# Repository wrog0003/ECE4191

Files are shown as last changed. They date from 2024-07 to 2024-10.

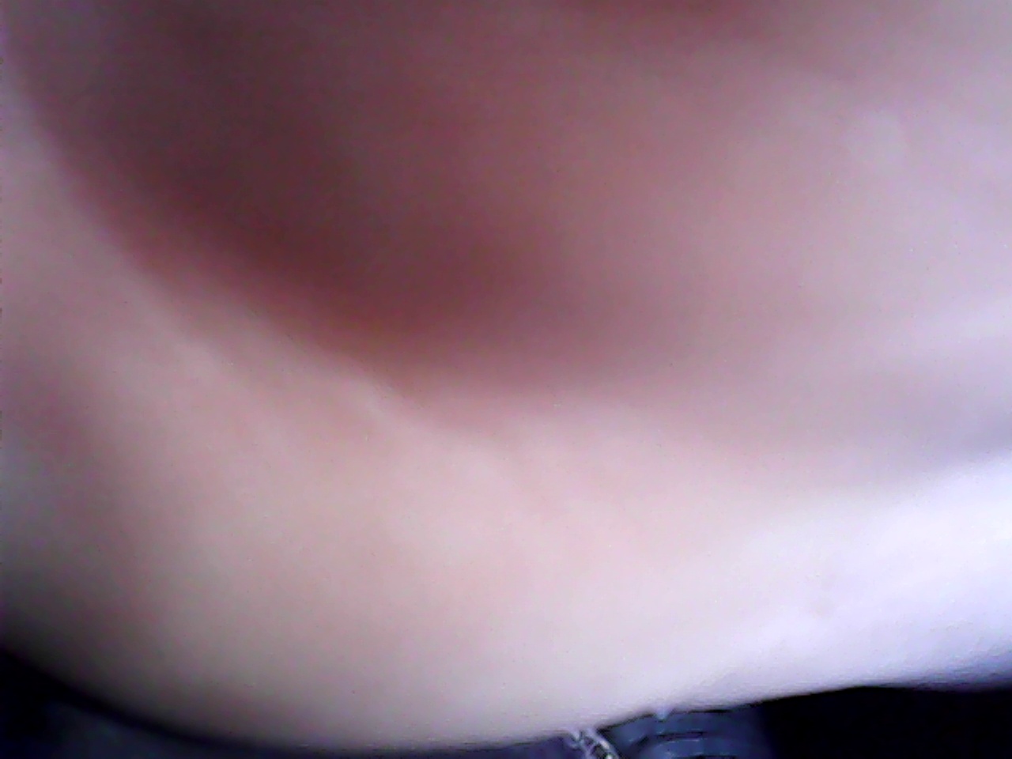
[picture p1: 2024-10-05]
Camera_code/Rpi_Cam.jpg

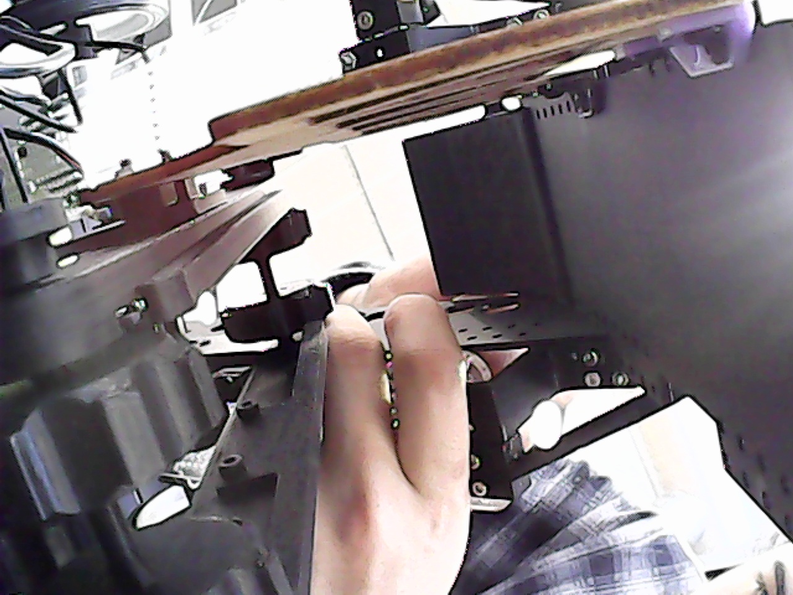
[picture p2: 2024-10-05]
Camera_code/Logitech_Cam.jpg

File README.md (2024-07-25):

# ECE4191
code and other bits and pieces for the project

## Members
Warren Rogan
Emma Vladicic
Richard Owen
Josh Taylor
Ryan Finette

## Purpose
Including all code for ECE4191

## Using rpi 
1. install the vs code extenstion Remote ssh
2. use remote connect to connect to the rpi, make sure you're on the same network 
3. use group23@ECE244
4. password is 1234
5. this will allow you to use the rpi headless

## using git
### own device
download github desktop, this app makes thing much easier
1. Open github desktop and make sure you're in the corect repo
2. Click fetch origin
3. Click this again if there is a pull orign message
4. ensure the pull is successful
5. Code 
6. When finished add a message to the commit entry and press commit
7. Click push 
8. make sure push works
9. done

### rpi
1. open terminal and navigate to the repo top directory
2. run git pull
3. make sure its succesful
4. code
5. when finished open terminal in repo top directory
6. run git commit -a 
7. add a commit comment and press ctrl s
8. press ctrl x to exit nano
9. run git push 
10. make sure this works 
11. done

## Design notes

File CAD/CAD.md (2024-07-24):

# ECE4191
CAD files for the project

## Conventions
### File naming

### 

## Purpose
Including all CAD for ECE4191

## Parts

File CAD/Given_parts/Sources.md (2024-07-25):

# ECE4191
CAD files for parts given as part of kit

Raspberry pi zero W: https://grabcad.com/library/raspberry-pi-zero-w-board-1

Raspberry pi 4: https://www.thingiverse.com/thing:4621310/files#google_vignette

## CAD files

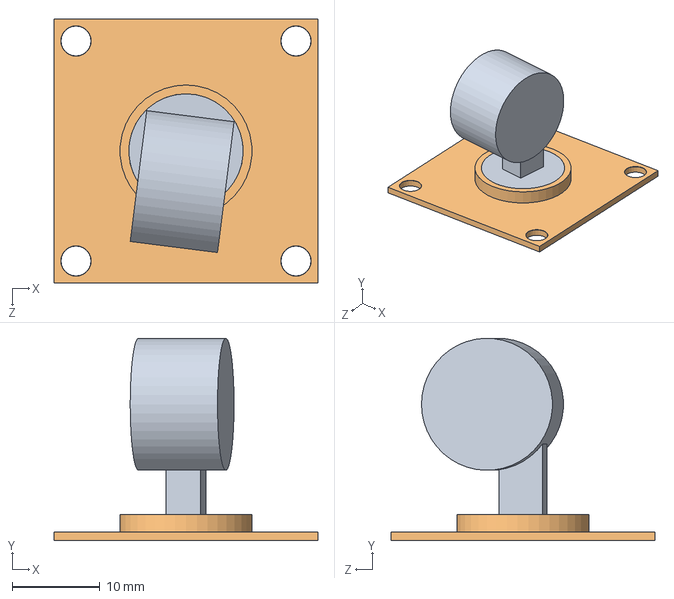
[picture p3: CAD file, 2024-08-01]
CAD/Given_parts/Wheels_Secondary.SLDASM
30.0 x 23.0 x 30.0 mm
Wheels_Secondary_Bottom
Wheels_Secondary_Top

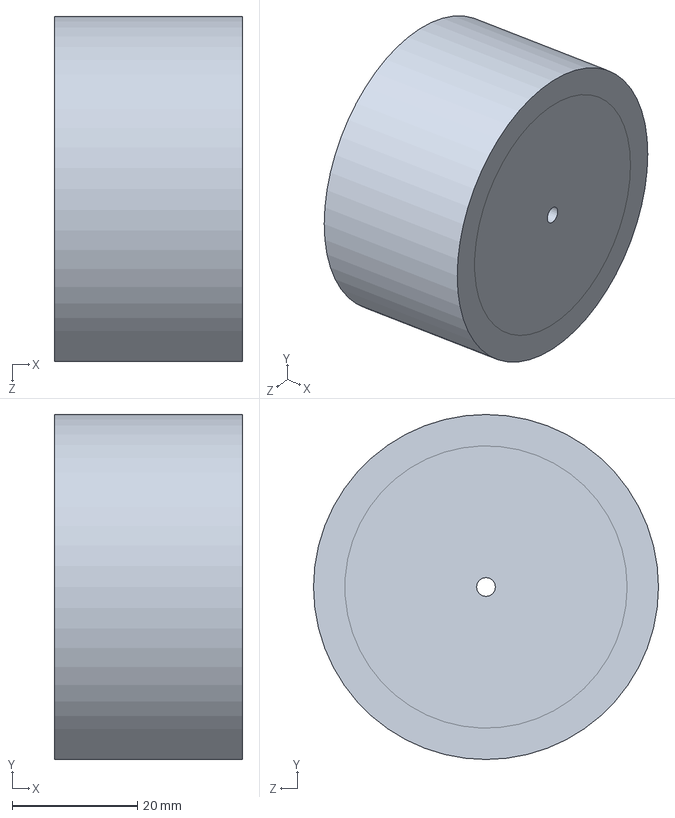
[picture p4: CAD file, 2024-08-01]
CAD/Given_parts/Wheels_Main.SLDPRT
30.0 x 55.0 x 55.0 mm

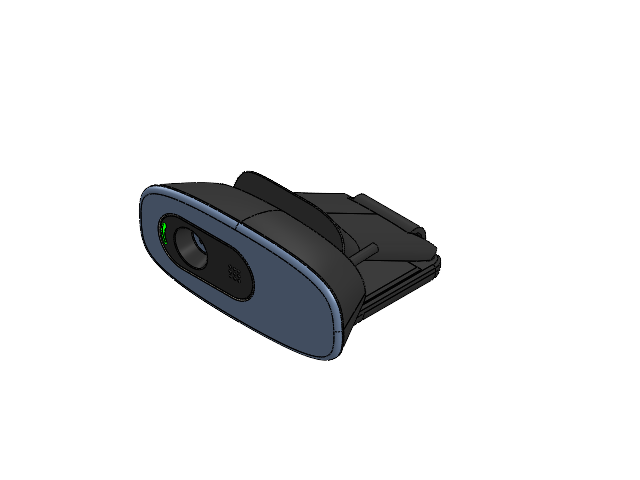
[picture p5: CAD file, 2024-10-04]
CAD/Given_parts/Logitech c270 Assembly.SLDASM
Logitech c270c
Logitech c270b
Logitech c270
Pin camera Mtg Plastic Logi c270

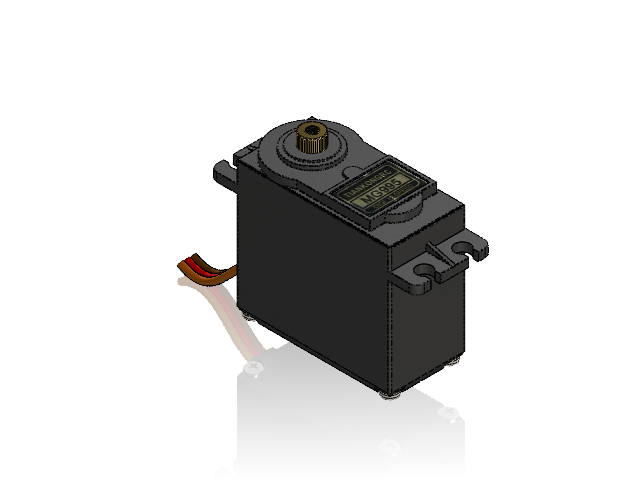
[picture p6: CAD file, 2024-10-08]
CAD/Given_parts/MG995/MG995 Assembly.SLDASM
MG995
Shaft
Wire Boot
Wires
pan head tapping screw_am x 4

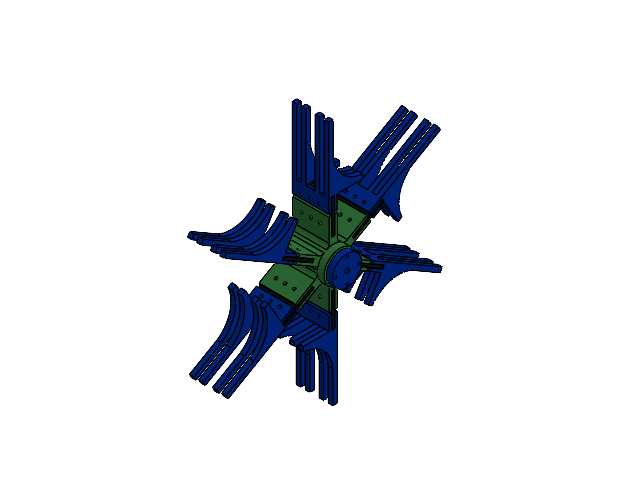
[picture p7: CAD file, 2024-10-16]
CAD/Self_designed_parts/HailMary/HM_Conveyer.SLDASM
HM_HUBCENTRE
HM_HUBCAP
HM_HUBEND
HM_HUBPLATE x 6
HM_HUBCLAW x 6

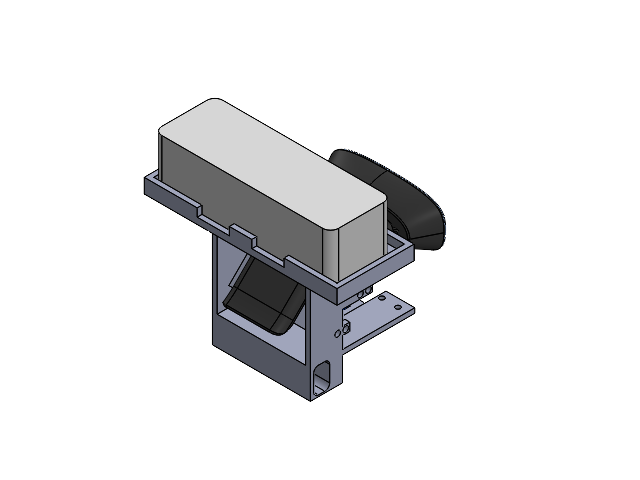
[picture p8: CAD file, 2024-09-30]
CAD/Self_designed_parts/CameraMountSection/CameraMountAss.SLDASM
Battery
NewServoMountSpacer
ServoMount
9gMicroServo
CameraMountBase
CameraMountClamp
Logitech c270
Logitech c270b
Logitech c270c
LipoHolder

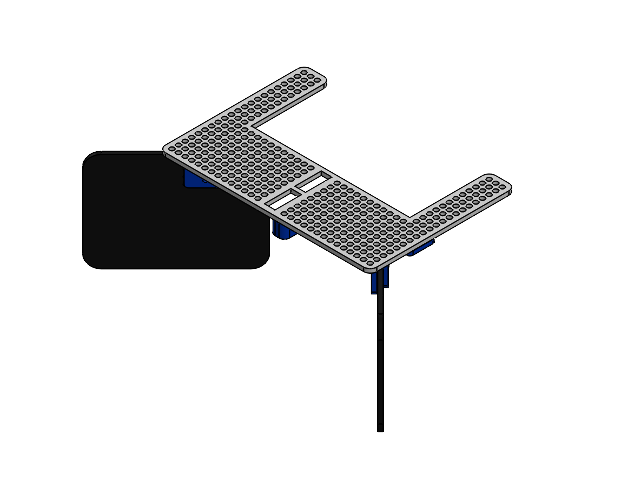
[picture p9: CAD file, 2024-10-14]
CAD/Self_designed_parts/FunnelMount/FunnelAssembally.SLDASM
FunnelPlate
FunnelAdaptor x 4
Funnel x 2
ButtonHolder

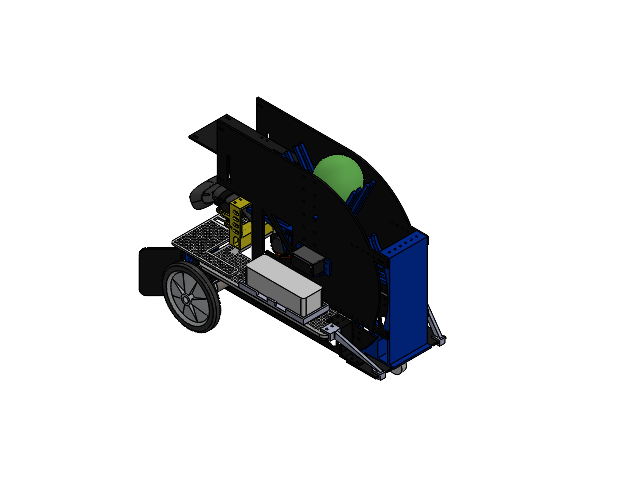
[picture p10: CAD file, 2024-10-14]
CAD/Self_designed_parts/HailMary/HaiMaryAssembly.SLDASM
25d-metal-gearmotor-75-99-encoder.step x 2
MotorMountBracket x 2
MotorMountSpacer x 2
Baseplate
Wheels_Secondary_Bottom
Wheels_Secondary_Top
RampWheelBracket
NewServoMountSpacer
L_Bracket_Chute x 4
BallChute x 2
RearMountBracket_Left
RearMountBracket_Right
Wheel_100mm x 2
MotorMount_Helper x 2
TennisBall(Max)
CameraMountBase
CameraMountClamp
Logitech c270c
Logitech c270b
Logitech c270
Pin camera Mtg Plastic Logi c270
LipoHolder
Battery
MG995
Shaft
Wire Boot
Wires
pan head tapping screw_am x 4
Servo_MG995_Star_horn
SupportBracket x 2
HM_SidePate
HM_HUBCENTRE
HM_HUMCAP
HM_HUBEND
HM_HUBPLATE x 6
HM_HUBCLAW x 6
HM_PLATEMOUNTER
HM_HUDSERVOMOUNT
HM_LOWERRAMP
HM_SidePateRIGHT
HM_ROLLPLATE
HM_UPPERRAMPHOLDER x 2
HM_RAMPADJUSTER x 2
FunnelPlate
FunnelAdaptor x 4
Funnel x 2
ButtonHolder

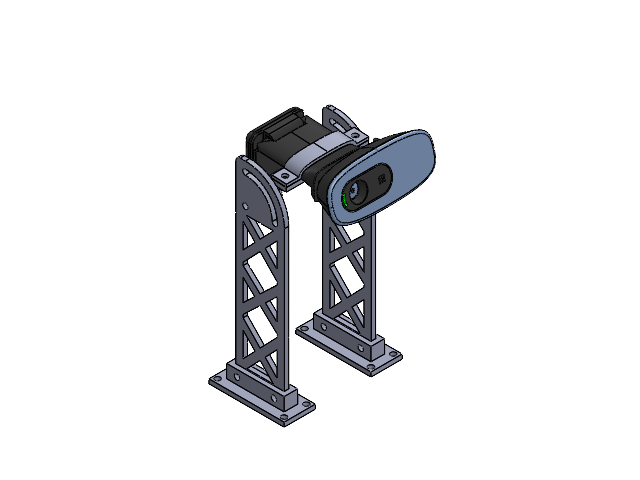
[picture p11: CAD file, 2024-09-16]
CAD/CameraMount/CM_ASS.SLDASM
CM_Base x 2
CM_Vertical x 2
Logitech c270c
Logitech c270b
Logitech c270
Pin camera Mtg Plastic Logi c270
CameraMountClamp
CameraMountBase

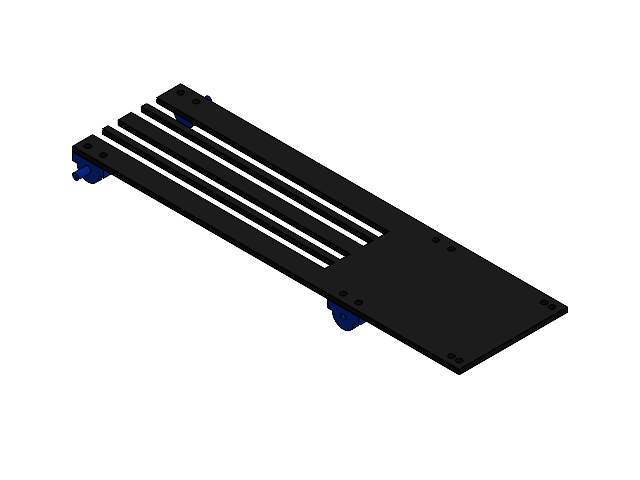
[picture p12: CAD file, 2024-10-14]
CAD/Self_designed_parts/HailMary/HM_RAMP_ASS.SLDASM
HM_ROLLPLATE
HM_UPPERRAMPHOLDER x 2
HM_RAMPADJUSTER x 2

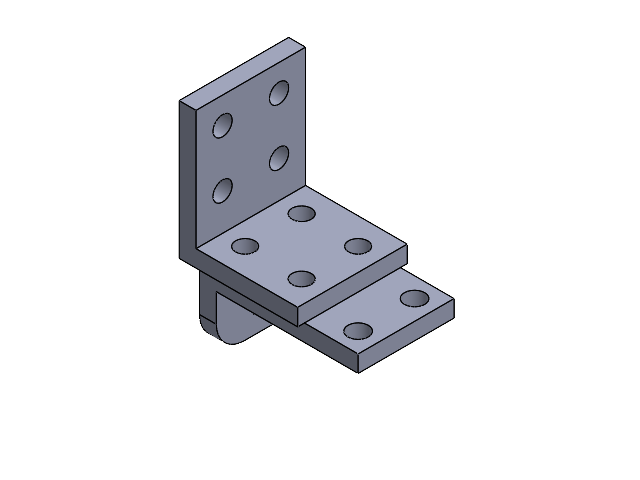
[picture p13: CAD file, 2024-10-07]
CAD/Self_designed_parts/TrackPincherTEST.SLDASM
L_Bracket_Chute
GearMount

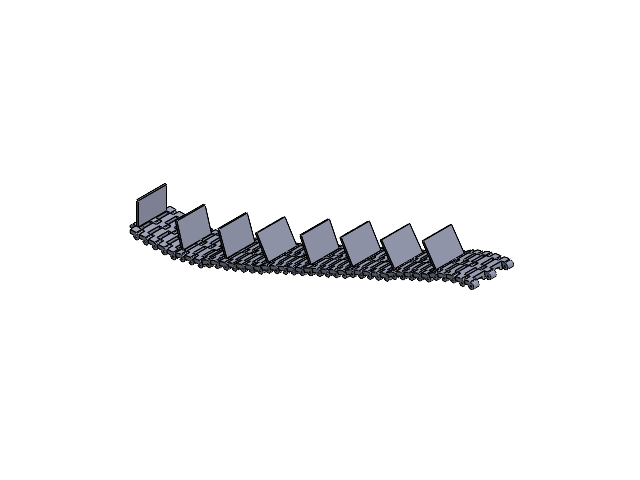
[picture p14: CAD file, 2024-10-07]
CAD/Self_designed_parts/TrackAssembly.SLDASM
Track_2.2_70mm_Pusher x 8
Track_2.2_70mm x 32

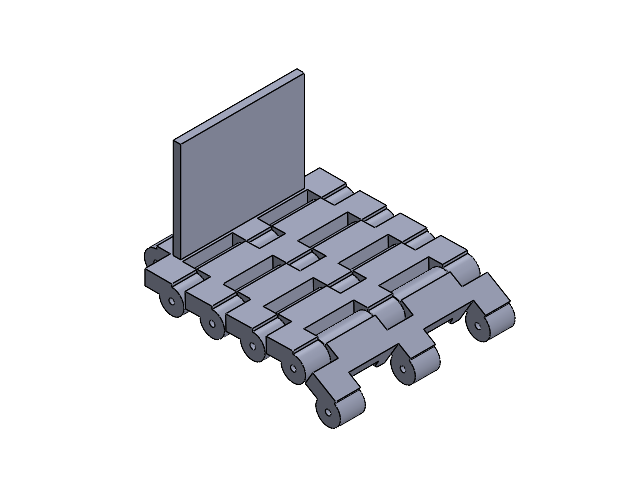
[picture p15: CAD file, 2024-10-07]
CAD/Self_designed_parts/TrackSegment.SLDASM
Track_2.2_70mm_Pusher
Track_2.2_70mm x 4

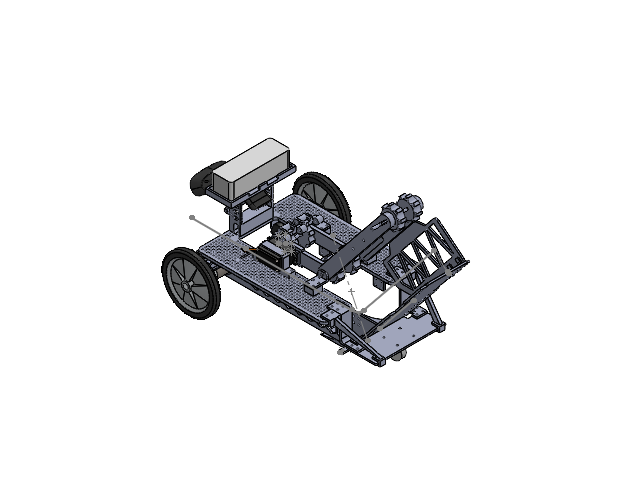
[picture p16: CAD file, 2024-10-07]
CAD/Self_designed_parts/RobotWholeAssembly.SLDASM
25d-metal-gearmotor-75-99-encoder.step x 2
MotorMountBracket x 2
MotorMountSpacer x 2
Baseplate
BallChute
Ramp
Wheels_Secondary_Bottom
Wheels_Secondary_Top
RampWheelBracket
NewServoMountSpacer
L_Bracket_Chute x 4
AngledRampBracket_Left
RearMountBracket_Left
RearMountBracket_Right
GearMount x 3
HorizontalGearSpacer x 2
GearMountSpacer x 3
Wheel_100mm x 2
MotorMount_Helper x 2
DiagonalGearSpacer x 2
RampChute
Track_Gear x 4
Axle x 3
Axle_Cap x 5
RampChuteBracket x 2
RampChuteSpacer
CameraMountBase
CameraMountClamp
Logitech c270c
Logitech c270b
Logitech c270
Pin camera Mtg Plastic Logi c270
LipoHolder
Battery
RampTrackChuck
MG995
Shaft
Wire Boot
Wires
pan head tapping screw_am x 4
Servo_MG995_Star_horn
MG995 Clamp
MG995 Mount
SupportBracket x 2
RampFix
Track_2.2_70mm
Track_Gear_NEW x 2
TrackPincher x 2

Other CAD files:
CAD/Self_designed_parts/ClawLeftAssembly.SLDASM
CAD/Self_designed_parts/ClawRightAssembly.SLDASM
CAD/Self_designed_parts/AlignmentAssembly_GearServo.SLDASM
CAD/Self_designed_parts/PusherAssembly.SLDASM
CAD/CameraMount/CM_Base.SLDPRT
CAD/CameraMount/CM_Mount.SLDPRT
CAD/CameraMount/CM_Vertical.SLDPRT
CAD/CameraMount/CameraLifter.SLDPRT
CAD/CameraMount/CameraLifter.STL
CAD/CameraMount/CameraMountBase.SLDPRT
CAD/CameraMount/CameraMountClamp.SLDPRT
CAD/Drawings/HM_HUBCAP.SLDDRW
CAD/Drawings/HM_HUBCENTRE.SLDDRW
CAD/Drawings/HM_HUBCLAW.SLDDRW
CAD/Drawings/HM_HUBEND.SLDDRW
CAD/Drawings/HM_HUBPLATE.SLDDRW
CAD/Drawings/HM_LOWERRAMP.SLDDRW
CAD/Given_parts/Baseplate.SLDPRT
CAD/Given_parts/Logitech c270.SLDPRT
CAD/Given_parts/Logitech c270b.SLDPRT
CAD/Given_parts/Logitech c270c.SLDPRT
CAD/Given_parts/MG90S horn.SLDPRT
CAD/Given_parts/MG90S horn.STEP
CAD/Given_parts/MG995/MG995.SLDPRT
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

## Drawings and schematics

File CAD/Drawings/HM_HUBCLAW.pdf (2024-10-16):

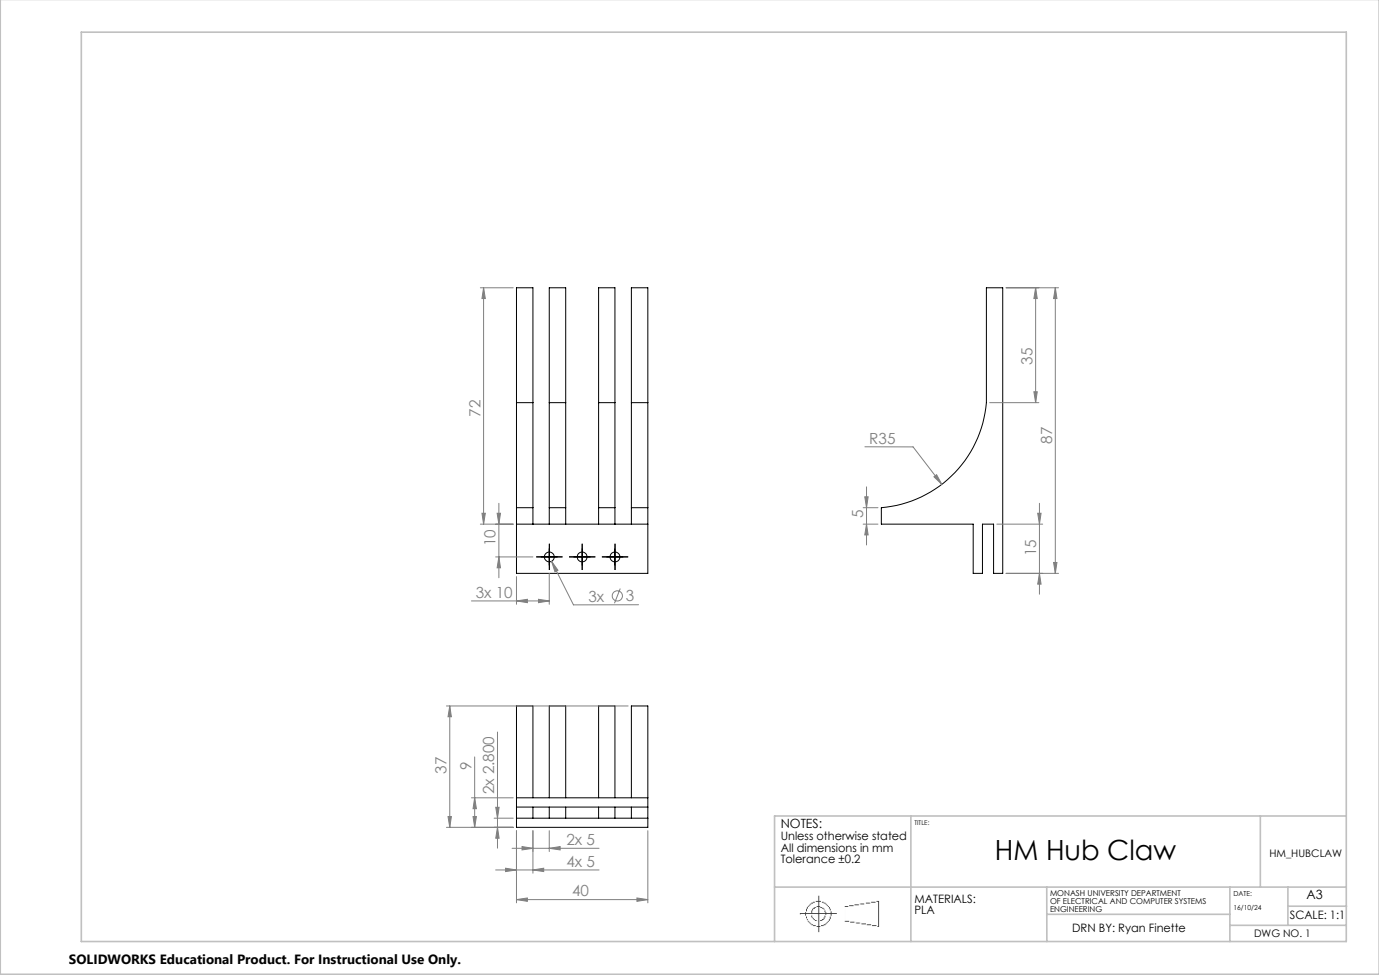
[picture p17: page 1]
DWG NO. 1; SCALE: 1:1

NOTES: Unless otherwise stated All dimensions in mm Tolerance ±0.2 | TITLE: HM Hub Claw | HM_HUBCLAW

MATERIALS: PLA | MONASH UNIVERSITY DEPARTMENT OF ELECTRICAL AND COMPUTER SYSTEMS ENGINEERING | DATE: 16/10/24 | A3

DRN BY: Ryan Finette

SOLIDWORKS Educational Product. For Instructional Use Only.

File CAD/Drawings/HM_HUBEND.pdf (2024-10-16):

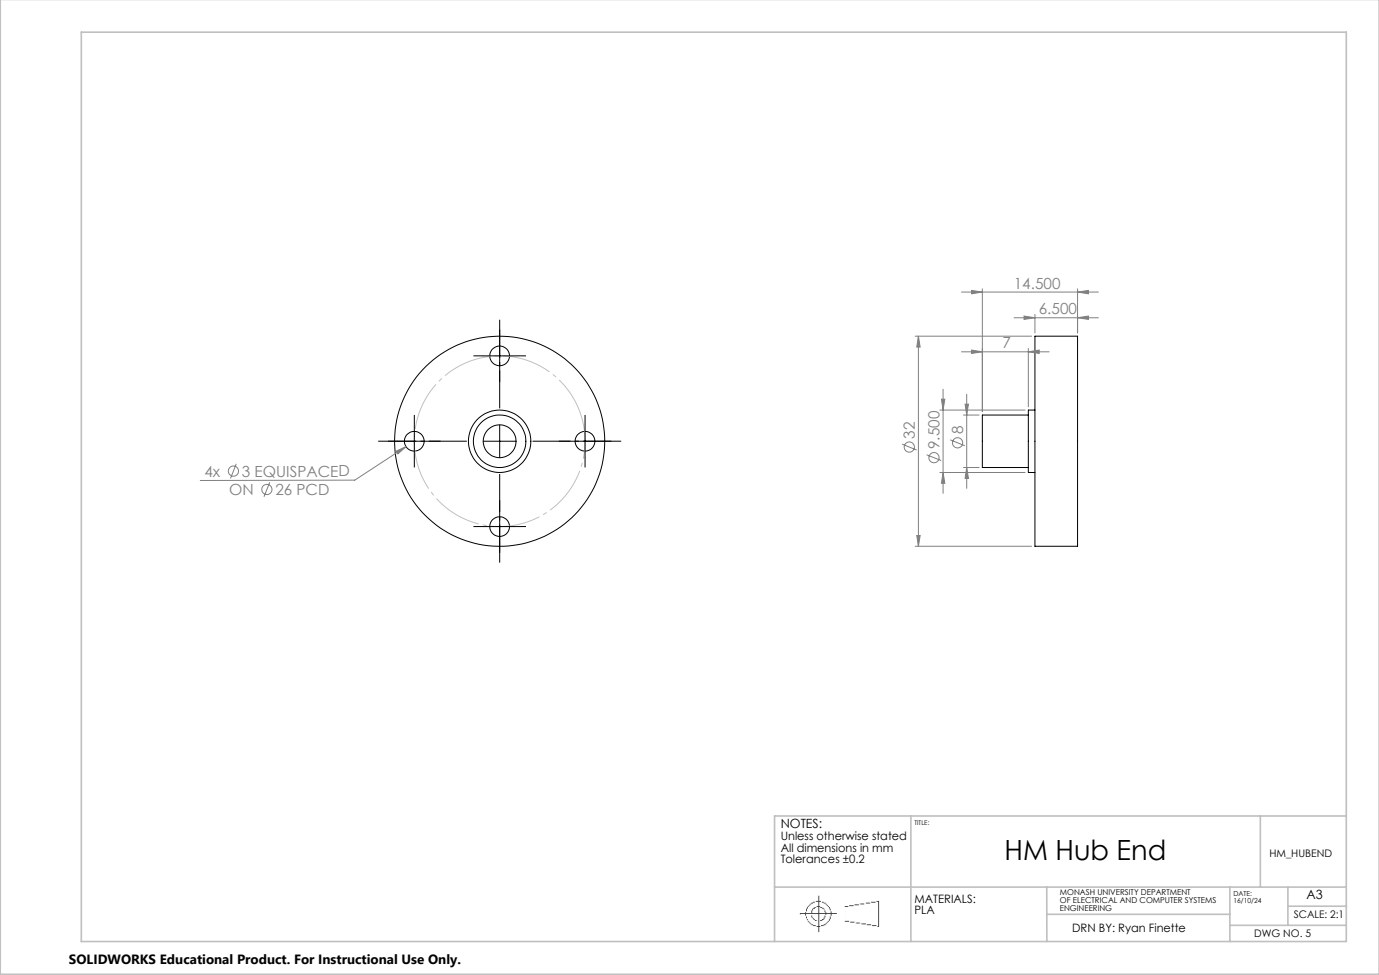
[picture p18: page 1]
4x 3 EQUISPACED ON 26 PCD; DWG NO. 5; SCALE: 2:1

NOTES: Unless otherwise stated All dimensions in mm Tolerances ±0.2 | TITLE: HM Hub End | HM_HUBEND

MATERIALS: PLA | MONASH UNIVERSITY DEPARTMENT OF ELECTRICAL AND COMPUTER SYSTEMS ENGINEERING | DATE: 16/10/24 | A3

DRN BY: Ryan Finette

SOLIDWORKS Educational Product. For Instructional Use Only.

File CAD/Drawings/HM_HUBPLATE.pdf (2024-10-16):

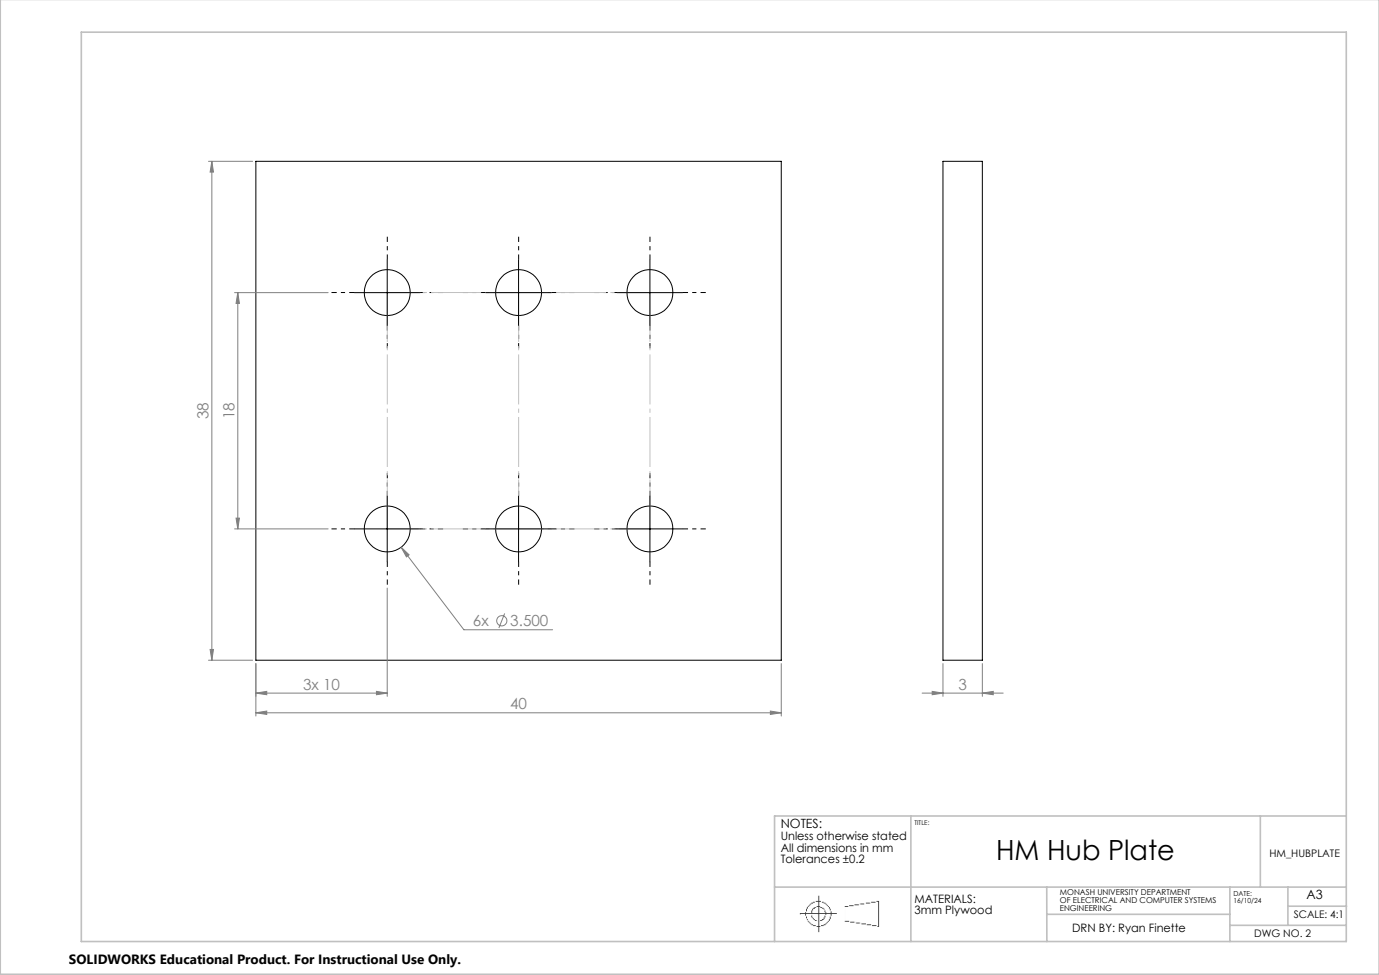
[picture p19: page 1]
DWG NO. 2; SCALE: 4:1

NOTES: Unless otherwise stated All dimensions in mm Tolerances ±0.2 | TITLE: HM Hub Plate | HM_HUBPLATE

MATERIALS: 3mm Plywood | MONASH UNIVERSITY DEPARTMENT OF ELECTRICAL AND COMPUTER SYSTEMS ENGINEERING | DATE: 16/10/24 | A3

DRN BY: Ryan Finette

SOLIDWORKS Educational Product. For Instructional Use Only.

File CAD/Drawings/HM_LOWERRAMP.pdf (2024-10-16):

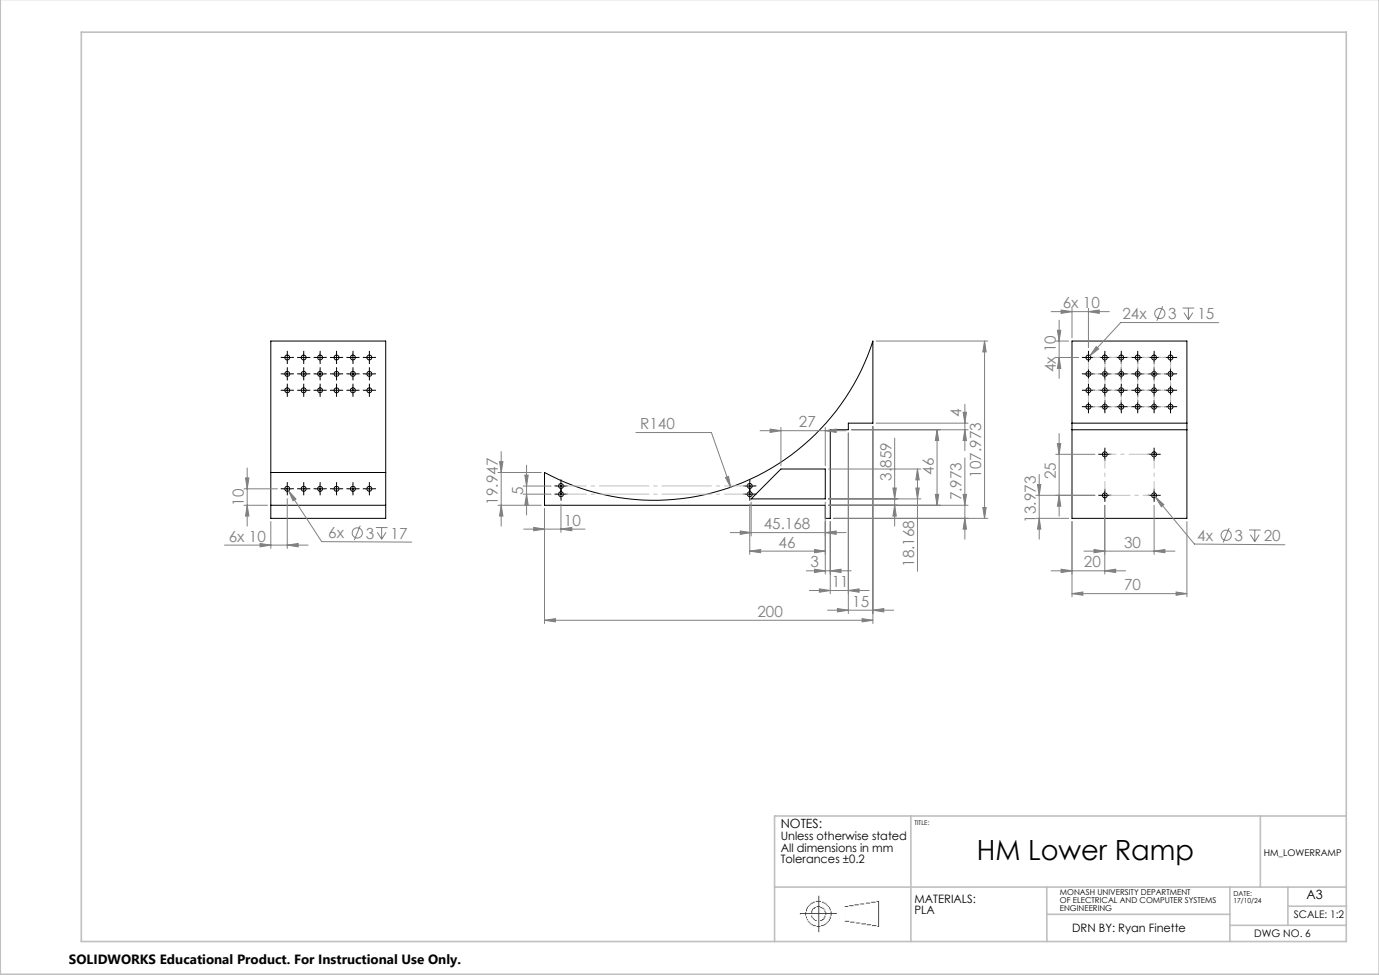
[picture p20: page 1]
DWG NO. 6; SCALE: 1:2

NOTES: Unless otherwise stated All dimensions in mm Tolerances ±0.2 | TITLE: HM Lower Ramp | HM_LOWERRAMP

MATERIALS: PLA | MONASH UNIVERSITY DEPARTMENT OF ELECTRICAL AND COMPUTER SYSTEMS ENGINEERING | DATE: 17/10/24 | A3

DRN BY: Ryan Finette

SOLIDWORKS Educational Product. For Instructional Use Only.

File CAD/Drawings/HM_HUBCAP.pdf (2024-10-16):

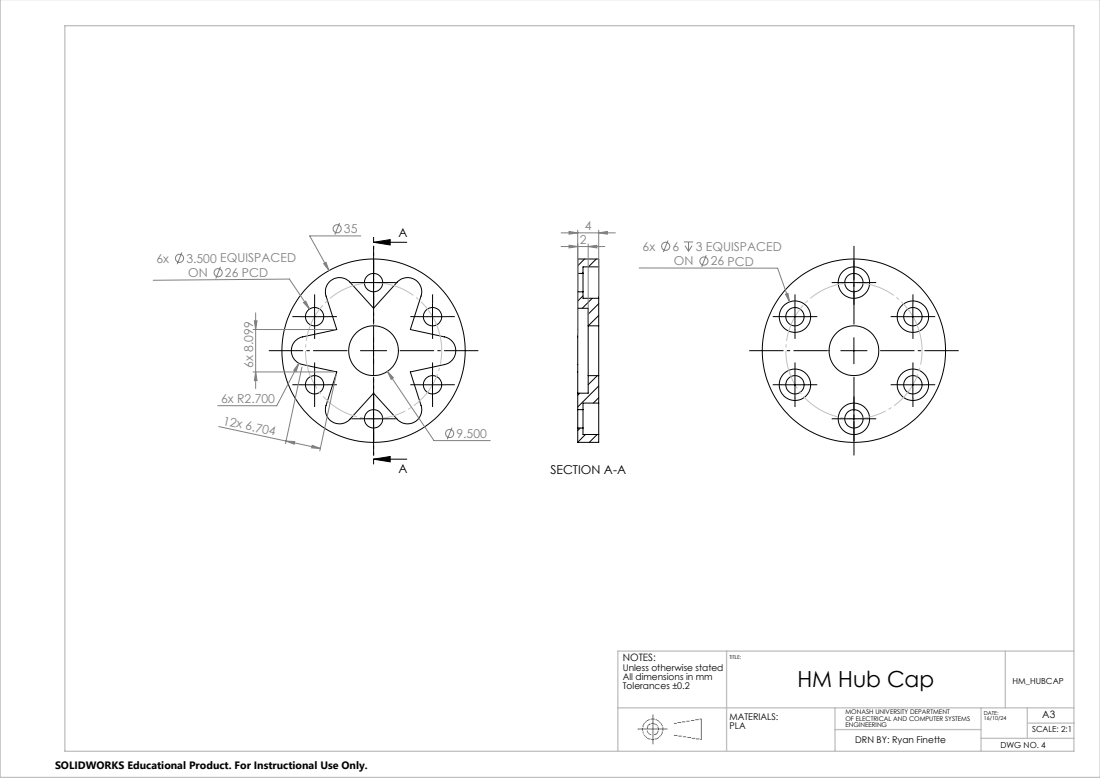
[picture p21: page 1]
6x 3.500 EQUISPACED ON 26 PCD; SECTION A-A; 6x 6 3 EQUISPACED ON 26 PCD; DWG NO. 4; SCALE: 2:1

NOTES: Unless otherwise stated All dimensions in mm Tolerances ±0.2 | TITLE: HM Hub Cap | HM_HUBCAP

MATERIALS: PLA | MONASH UNIVERSITY DEPARTMENT OF ELECTRICAL AND COMPUTER SYSTEMS ENGINEERING | DATE: 16/10/24 | A3

DRN BY: Ryan Finette

SOLIDWORKS Educational Product. For Instructional Use Only.

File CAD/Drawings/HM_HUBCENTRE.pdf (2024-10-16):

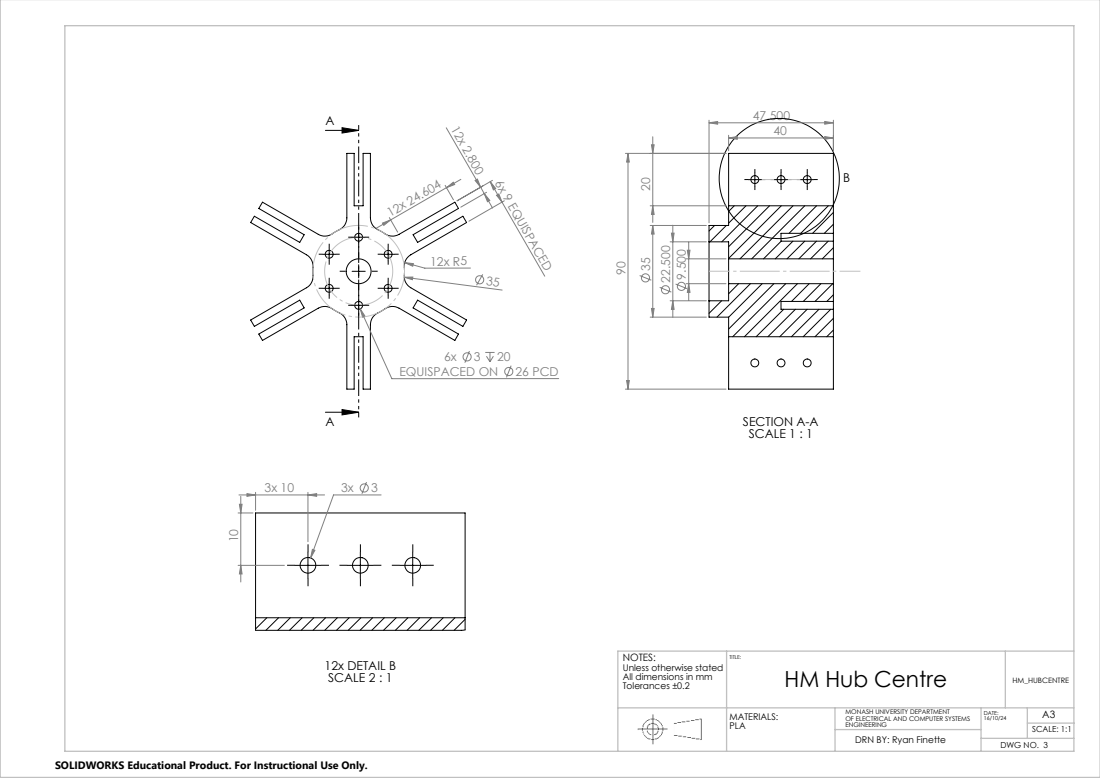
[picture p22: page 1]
6x 9 EQUISPACED; SECTION A-A SCALE 1 : 1; 12x DETAIL B SCALE 2 : 1; DWG NO. 3; SCALE: 1:1

EQUISPACED ON 26 PCD

NOTES: Unless otherwise stated All dimensions in mm Tolerances ±0.2 | TITLE: HM Hub Centre | HM_HUBCENTRE

MATERIALS: PLA | MONASH UNIVERSITY DEPARTMENT OF ELECTRICAL AND COMPUTER SYSTEMS ENGINEERING | DATE: 16/10/24 | A3

DRN BY: Ryan Finette

SOLIDWORKS Educational Product. For Instructional Use Only.

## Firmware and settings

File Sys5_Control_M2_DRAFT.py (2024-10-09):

# overall brains script for robot, written by Emma Vladicic and Warren Rogan 

from ECE4191enums import STATE, DIRECTION, ACTION
from Motor_code.encoderClass import SimpleEncoder
from Sys4_Vision import Sys4_Vision
from Box_detection.box_detection import find_and_goto_box
from gpiozero import Button
from SysC_BallCollection import SysC_BallCollection

from time import sleep, time 
from math import pi, atan2, sqrt, sin, cos

from typing import Tuple

import RPi.GPIO as GPIO
import GLOBALSM1 # for physical values of the robot i.e. wheel diameter, distance b/w wheeels etc   

# Define important variables 

# Define clockwise and anti-clockwise as Boolean variables 
ANTICLOCKWISE = False
CLOCKWISE = True

# Define physical GPIO pins on the Rpi 
# Motor Left (to drive motors)
motor1a = 23
motor1b = 24

# Motor Right (to drive motors)
motor2a = 17
motor2b = 27

# Encoder Left (to recieve data from encoders)
motor1cha = 13
motor1chb = 19

# Encoder Right (to recieve data from encoders)
motor2cha = 5
motor2chb = 6



# Wheel bias (used to callibrate differences in wheel movement)
#duty_cycle_bias = 0.963 


#Milestone 1 control top level class 

class Sys5_Control:

    # initialisation of the class
    def __init__(self) -> None:
        '''
        This setups up the variables needed to make an instance of the class
        It completes the following:

            1. Set GPIO pinmode 
            2. Set GPIO motor pin types
            3. Sets motor pins as PWM instance variables
            4. Creates instance variables
                4.0. for Vision class instance
                4.1. for position and rotation
                4.2. for internal state
                4.3. to keep track of encoder mismatch count
                4.4. and defines to define starting motor bias
                4.5. 2 instances of the encoder class
                4.6. an active motor PWM pin and desired duty cycle copy
        '''

        GPIO.setmode(GPIO.BCM) # set pin types 

        # Set up the motor output pins 
        GPIO.setup(motor1a, GPIO.OUT) 
        GPIO.setup(motor1b, GPIO.OUT)
        GPIO.setup(motor2a, GPIO.OUT)
        GPIO.setup(motor2b, GPIO.OUT)

        # Set up the PWM pins
        self.pwm1a = GPIO.PWM(motor1a,500)
        self.pwm1b = GPIO.PWM(motor1b,500)
        self.pwm2a = GPIO.PWM(motor2a,500)
        self.pwm2b = GPIO.PWM(motor2b,500)
        self.pwm1a.stop()
        self.pwm1b.stop()
        self.pwm2a.stop()
        self.pwm2b.stop()

        # Pin to receive interrupts from limit switch whenever a ball is collected
        self.ballDetected = Button(22, pull_up=True, bounce_time = 0.02)

        

        self.boxHit = Button(10, pull_up=True, bounce_time = 0.02)
        
        self.boxHasBeenHit = False 
        
        # initalise the vision system
        self.vision = Sys4_Vision()

        #Position control
        # define the initial position of the robot as (0,0) with a rotation of 0 
        self.x_pos =0
        self.y_pos = 0
        self.rot = 0 

        self.State = None # State is the movement of the robot i.e. Left, Right, Forward, Backward
        '''The current state of the robot, Forwards, Backward, Left, Right or None'''
        # initalise to none bc robot is not moving

        # Keeps track of difference in encoder pulse counts. 
        self.error_count = 0

        # Apllies a bias to the right motor to increase or decrease its output speed to ensure straight line motion.
        self.duty_cycle_bias = 0.963

        self.EncoderL = SimpleEncoder(motor1cha,motor1chb) # set up Left Motor
        self.EncoderR = SimpleEncoder(motor2cha,motor2chb) # set up right Motor

        #PI controller access variables
        self.duty_cycle = 0  # allows access for the PI controller 
        self.RActivePin = None # allows correct motor access to the controller 

        # Self variables to keep track of the number of balls collected and the capacity of the conveyor storage. 
        self.capacity = 2 # Maximum number of tennis balls that can be stored in the conveyor system. 
        self.numBalls = 0 # Number of balls collected by the robot on any given run.  
        self.ballCollection = SysC_BallCollection(12,9)
        self.cycles = 0 
        '''Number of cycles completed, should never get higher than 2'''


        # Timeout flag to tell the robot when to return to home and how long it should collect and deposit balls for 
        self.timeout = False 
        
        self.endtime = time() + 60*9
        ''' sets the time at which the robot will stop search for balls and depoit them'''

            
    def _forwards(self,duty_cycle:float)->ACTION:
        '''
        This private function sets the motors to move forwards at a desired speed. 

        Inputs:
            self: class instance
            duty_cycle: the speed, from 0-100

        Output:
            the internal state of the robot, used for updating the position and rotation
        '''
        # duty cycle = controls speed of robot (0 - 100)
        # output: return the state of the robot
        print("x")
        # drive the motor forwards 
        self.pwm1a.start(0)
        self.pwm2a.start(0)
        self.pwm1b.start(duty_cycle)
        self.pwm2b.start(max(duty_cycle*self.duty_cycle_bias,5))
        self.duty_cycle = duty_cycle
        self.RActivePin = self.pwm2b


        return ACTION.FORWARD

    def _backwards(self, duty_cycle:float)->ACTION:
        '''
        This private function sets the motors to move backwards at a desired speed. 

        Inputs:
            self: class instance
            duty_cycle: the speed, from 0-100

        Output:
            the internal state of the robot, used for updating the position and rotation
        '''
        # duty cycle = controls speed of robot (0 - 100)
        # output: return the state of the robot

        self.pwm1b.start(0)
        self.pwm2b.start(0)
        self.pwm1a.start(duty_cycle)
        self.pwm2a.start(max(duty_cycle*self.duty_cycle_bias,5))
        self.duty_cycle = duty_cycle
        self.RActivePin = self.pwm2a

        return ACTION.BACKWARD 

    def _turn(self,duty_cycle:float,clockWise:bool)->ACTION:

        '''
        This private function sets the motors to turn left or right at a desired speed

        Inputs:
            self: a class instance
            duty_cycle: the speed, from 0-100
            clockWise: if it should turn clockwise, use False if turing anticlockwise

        Output:
            the internal state of the robot, used for updating the position and rotation
        
        This function checks if it is clockwise or anticlockwise and turns on the correct motors to achieve this movement.
        It also saves which pin of the right motor is active and the desired duty cycle for use in the PI controller.  
        '''
        # input: 
        # duty cycle = controls speed of robot (0 - 100)
        # bool = dirction to turn, clockwise or anticlockwise 
        # output: return the state of the robot
        
        if clockWise: # turn clockwise 
            self.pwm1a.start(0)
            self.pwm2b.start(0)
            self.pwm1b.start(duty_cycle)
            self.pwm2a.start(max(duty_cycle*self.duty_cycle_bias,5))
            self.duty_cycle = duty_cycle
            self.RActivePin = self.pwm2a
            return ACTION.RIGHT
        else: # turn anti-clockwise
            self.pwm1b.start(0)
            self.pwm2a.start(0)
            self.pwm1a.start(duty_cycle)
            self.pwm2b.start(max(duty_cycle*self.duty_cycle_bias,5))
            self.duty_cycle = duty_cycle
            self.RActivePin = self.pwm2b
            return ACTION.LEFT
        

    def _stop(self)->None: # stop movement of robot
        '''
        This private function stops all the motors to prevent unplanned movement.
        ''' 
        self.pwm1a.stop()
        self.pwm1b.stop()
        self.pwm2a.stop()
        self.pwm2b.stop()
        # does not include a state update as the robot may continue moving for a short period as it has interia

    # Manual exit function to prevent loss of pin control
    def __del__(self)->None:
        '''
        This private function is used to allow for manual exit of code if needed by disconnecting from peripherals.

        Inputs: 
            self: class instance

        It stops the motors, disconnects the motor GPIO pins, disconnects the encoders pins, and disconnects the camera feed. 
        '''
        self._stop()
        GPIO.cleanup()
        del self.EncoderL
        del self.EncoderR
        del self.vision  
    
    # Release all Pins


    # Position tracking 
    def _updatePos(self, x_old:float, y_old:float, rot_old:float)->list[float]:
        '''
        This private function updates the internal position of the robot and runs the PI controller

        Inputs:
            self: an instance of this class
            x_old: the old x location (m)
            y_old: the old y location (m)
            rot_old: the old rotation (degrees)

        Outputs:
            new x: updated x location (m)
            new y: updated y location (m)
            new rot: updated rotation (degrees)

        This uses the internal state of the robot and the change in encoder counts to update position. 
        The internal state is defined based on direction calls that determines how the change in positions is updated.
        For forwards and backwards it maintains the rotation, and then uses sin and cos to add to x and y
        For turning it uses the track width to work out the angle change and adds it to the current angle. It maintains the x and y pos
        '''

        # inputs 
        # self = direction that the robot is moving 
        # x_old, y_old, rot_old = previous x, y coordinate and rotation of robot

        # output 
        # x, y, rot = current x, y  coordinates and rotation of robot

        # get the number of pulses the encoder has counted
        [newL, dirL, oldL] = self.EncoderL.getValues()
        [newR, dirR, oldR] = self.EncoderR.getValues()

        # calculate the difference in the number of encoder pulses in the time between the last call
        delL = abs(newL-oldL)
        delR = abs(newR-oldR)
        #print(delL-delR)
        
        #Call the encoder controller method
        #if self.State == ACTION.FORWARD or self.State ==ACTION.BACKWARD:
        self.EncoderController(delL, delR)
        #print(self.duty_cycle_bias)
        # calculate the average travelled distance 
        distanceAvg = ((delL*GLOBALSM1.distancePerPulse)+(delR*GLOBALSM1.distancePerPulse))/2 
    
        # reset coordinates and rotation to 0 
        x = 0
        y = 0 
        rot = 0 

        # calculate the change in x, y and angle positions
        dx = distanceAvg*cos(rot_old*pi/180)
        dy = distanceAvg*sin(rot_old*pi/180)
        dtheta = distanceAvg*360/GLOBALSM1.wheelBaseCircumference
        # determine direction that the robot has travelled in the previous timestep & update coordinates
        if self.State == ACTION.FORWARD: 
            rot = rot_old
            y = y_old + dy 
            x = x_old + dx

        elif self.State == ACTION.BACKWARD:
            rot = rot_old
            y = y_old - dy
            x = x_old - dx

        elif self.State == ACTION.LEFT:
            x = x_old
            y = y_old
            rot = rot_old + dtheta

        elif self.State == ACTION.RIGHT:
            x= x_old
            y = y_old
            rot = rot_old - dtheta

        # limit the angle to the correct domain
        if rot > 180:
            rot -=360 
        elif rot <-180:
            rot +=360 
        #print(f'x{x},y{y},rot{rot}')
        return x,y,rot
    
#Improved sleep function to maintain localization and PI control 
    def _delay(self,delay_time:float)->None:
        '''
        This private delay function sleeps and runs localization.

        Inputs: 
            self: the class instance
            time: the time in seconds to delay, must be greater than 0.02
        
        Functionality:
            This breaks the time up into 0.02 second chunks and runs localization after each chunk. 
            This prevents error buildup. 
        '''

        if time() >= self.endtime:
            self.timeout = True 
        
        internalTime = 0
        cameraTime = 0
        while internalTime <delay_time: # while waiting
            sleep(0.02) #sleep
            self.x_pos, self.y_pos, self.rot = self._updatePos(self.x_pos,self.y_pos,self.rot) # update pos and call controller 
            internalTime+=0.02 # increment time 
            cameraTime +=0.02

            # every second check if line has been detected
            if cameraTime > 1:
                (direction, LinePresent, distance)= self.vision.detect() # run vision check
                cameraTime =0
                if LinePresent:
                    self.lineFoundResponse() #rotate
                    break #exit delay as it hasn't found the ball
        return 

    # Method that takes in the change in encoder pulses on the left and the right encoders and uses a controller to change the duty cycle bias.  
    def EncoderController(self, delL:int, delR:int) -> float:

        '''
        This function acts as a PI controller to ensure that the motor speeds are the same 

        Inputs:
            self: the class instance
            delL: change in left encoder count 
            delR: change in right encoder count 

        Outputs:
            duty_cycle_bias = biad applied to right encoder so that it matches speed of left motor 


        '''
        # Controller Gains (Proportional, Integral, Derivative)
        Kp = 0.375 # 1.4 is good 
        Ki = 0.17
        
        # Desired difference between the left and the right encoder counts when moving forwards. 
        reference = 0
        
        # Calculates a duty cycle bias to apply (Limited between 0.5 and 1)
        self.duty_cycle_bias = max(0.5,min((Kp*(reference-(delR-delL)) - Ki*self.error_count),1.2)) #PI controller 
        
        countDifference = (delR-delL) #get teh difference
        self.error_count += countDifference #add to the integral factor 

        self.RActivePin.start(max(self.duty_cycle*self.duty_cycle_bias,5))
        return 

    def hitBallSettings(self) -> Tuple[DIRECTION, float, float, bool]:
        '''
        Calls the vision system and determines the direction that the robot needs to move 
        the distance to the ball and if the robot will hit the ball in the next move 

        INPUTS
            self: the class instance

        OUTPUTS
            direction = direction that the robot is relative to the ball
            speed = speed that the robot should travel at in the next time step
            pauseTime = how long the robot should travel at this speed for 
            noHit = whether the ball will be hit by performing this movement 

        '''

        (direction, line_detected, distance)= self.vision.detect() # run vision check 

        noHit = True
        if (direction == DIRECTION.Ahead):

            # settings if robot if more than 0.55m away from the ball 
            speed = 70 # set the drive speed 
            pauseTime = 0.5 # how long in secs the robot should drive forwards for 

            if (distance <  0.6): # if robot is less than 0.55 m from ball 
                speed = 50 # reduce speed of robot
            
            if (distance < 0.30): # close to ball, drive forwards until you hit it
                print(distance)
                speed = 50 
                pauseTime = 3
                noHit = False

        elif (direction == DIRECTION.CannotFind):
            speed = 35
            pauseTime = 0.1

        else: # ball is in field of view but is either left or right
            speed = 35
            pauseTime = 0.1
        
        return direction, speed, pauseTime, noHit, line_detected
    
    def hitBall(self) -> None: 
        '''
        gets the robot to hit the ball once it is close enough

        Inputs: 
            self: the class instance 
        
        Outputs:
            none
        '''
        noHit = True 
        try:
            while(noHit): # while not close enough to the ball

                #print("no ball")

                # get the speed, pauseTime and if the robot will hit the ball in the next timestep
                direction, speed, pauseTime, noHit, line_detected = self.hitBallSettings() # inside this function, the vision check is run

                if (line_detected): # if line is detected, turn the robot to avoid the line, assigned the highest priority
                    print("line detected")
                    self.lineFoundResponse()
                
                else: # move to the ball 


                    # Ball AHEAD
                    if (direction == DIRECTION.Ahead):
                        self.State = self._forwards(speed)
                    
                    # Ball CANNOT FIND 
                    elif (direction == DIRECTION.CannotFind):
                        self._stop()
                        self.State = self._turn(speed, ANTICLOCKWISE)
                    
                    # Ball LEFT 
                    elif (direction == DIRECTION.Left):
                        self._stop()
                        self.State = self._turn(speed,ANTICLOCKWISE)
                    
                    # Ball RIGHT
                    else:
                        self._stop()
                        self.State = self._turn(speed,CLOCKWISE)
                
                self._delay(pauseTime)# do that movement for the designated n.o sec defined in PauseTime
                self._stop() # stop movement of robot temporarily until next action is determined
                # get position of robot 
                self.x_pos, self.y_pos, self.rot = self._updatePos(self.x_pos,self.y_pos,self.rot)

                if (self.timeout):
                    self._stop()
                    break
            self._forwards(speed)
            self.ballCollection.addBallToSystem()
            self.numBalls += 1
            self._forwards(50)
            self._delay(0.5)
            self._stop()
            
            print(f'Reached {self.x_pos}, {self.y_pos} with rot of {self.rot}\n')

            

        
        except KeyboardInterrupt: 
            self.__del__()
        
    def goToBoxSettings(self) -> Tuple[DIRECTION, float, float, bool]:
        '''
        Calls the vision system and determines the direction that the robot needs to move, 
        the distance to the box and if the robot will be in range of the box to start the deposit sequence.  

        INPUTS
            self: the class instance

        OUTPUTS
            direction = direction that the robot is relative to the box
            speed = speed that the robot should travel at in the next time step
            pauseTime = how long the robot should travel at this speed for 
            noHit = whether the box will be in range by performing this movement 

        '''
    
        (direction, line_detected, distance)= self.vision.detectBox() # run vision check 
        print(distance)
        noHit = True
        if (direction == DIRECTION.Ahead):

            # settings if robot if more than 0.55m away from the box 
            speed = 70 # set the drive speed 
            pauseTime = 0.5 # how long in secs the robot should drive forwards for 

            if (distance <  0.55): # if robot is less than 0.55 m from box 
                speed = 50 # reduce speed of robot
            
            if (distance < 0.18): # close to box, drive forwards until in range to deposit the ball 
                print("hitting")
                speed = 50 
                pauseTime = 3
                noHit = False

        elif (direction == DIRECTION.CannotFind):
            speed = 50
            pauseTime = 0.1

        else: # ball is in field of view but is either left or right
            speed = 30
            pauseTime = 0.1
        
        return direction, speed, pauseTime, noHit, line_detected

    def goToBox(self) -> None:
        '''
        gets the robot to approach the box once it is close enough

        Inputs: 
            self: the class instance 
        
        Outputs:
            none
        '''

        noHit = True 
        try:
            while(noHit): # while not close enough to the box

                # get the speed, pauseTime and if the robot will be in range of the box in the next timestep
                direction, speed, pauseTime, noHit, line_detected = self.goToBoxSettings() # inside this function, the vision check is run
                
                if (line_detected): # if line is detected, turn the robot to avoid the line, assigned the highest priority
                    self.lineFoundResponse()
                
                else: # move to the ball
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

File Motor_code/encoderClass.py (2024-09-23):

from gpiozero import Button, RotaryEncoder

# Set up a simple encoder class to track miltiple encoders on single system
class SimpleEncoder:
    '''
    A simple encoder class that connects to two pins and counts the number of rising edges on pin A
    '''
    # define initialisation parameters to set up all sections 
    def __init__(self,Apin:int,Bpin:int) -> None:
        '''
        This function creates an instance of the encoder class and sets up the pins
        
        Inputs:
            self: instance of the class
            Apin: the GPIO pin number to connected to the encoder
            Bpin: the second GPIO pin connected to the encoder, no longer in use
        '''
        self.Apin = Button(Apin, pull_up=True) # high = logic 1, low = logic 0
        #self.Bpin = Button(Bpin, pull_up=True) 
        self.encoderCount = 0 # initialise encoder count to 0 
        '''The number of encoder pulses current'''
        self.encoderOldCount = 0 
        '''The number of encoder pulses the last time the encoder was checked'''
    
        self.clockWise = False # facing in from outside
        #self.DirectionList = [self.clockWise]*3
        # set up interrupts (rising and falling)
        self.Apin.when_pressed = self.encoderCallA 
        #self.Bpin.when_pressed = self.encoderCallB

        #self.Apin.when_released = self.encoderCall
        #self.Bpin.when_released = self.encoderCall

    # interrupt callback functions
    def encoderCallA(self,channel):
        '''
        Callback function to increment the encoder count'''
        self.encoderCount+=1 # increment encoder count
        # if (self.Bpin.value):
        #     self.clockWise = True
        # else:
        #     self.clockWise = False

    def encoderCallB(self,channel):
        self.encoderCount+=1 # increment encoder count
        # if (self.Apin.value):
        #     self.clockWise = False
        # else:
        #     self.clockWise = True 

    # def encoderCall(self,channel):
    #     self.encoderCount+=1

    #get the state of the encoder, current count, direction, old count
    def getValues(self)->tuple[int,bool,int]:
        '''
        This function is used to pass distance information to the robots controller and update the old count
        
        Outputs:
            the current encoder count
            the direction (legacy)
            the old encoder count'''
        temp = self.encoderOldCount
        self.encoderOldCount = self.encoderCount
        return [self.encoderCount,self.clockWise,temp]
    
    #function call to relase pins
    def __del__(self)->None:
        '''
        This function releases control of the button instances to prevent lockup of the GPIO pins'''
        self.Apin.close()
        #self.Bpin.close() 

class BetterEncoder(RotaryEncoder):
    def __init__(self,Apin:int,Bpin:int)->None:
        RotaryEncoder.__init__(self,Apin,Bpin) # call the init of the parent class 
        self.encoderOldCount = 0 # create a save of the old encoder
    
    def getValues(self)->tuple[int,bool,int]:
        temp = self.encoderOldCount
        self.encoderOldCount = self.steps
        return [self.steps,True,temp]
    def end(self)->None:
        self.close()
     
# drive definitions 
#   L   R       direction
#   CCW CW      forward
#   CW  CCW     backward
#   CCW CCW     right
#   CW  CW      left

# Emma's attempt at using the rotary encoder class 

class Encoder:

    # initalise encoder 
    def _init_ (self,Apin:int,Bpin:int) -> None:
        self.encoderCount = 0 
        self.encoderOldCount = 0 
        RotaryEncoder(self, Apin, Bpin) # inialise the rotatry encoder from gpio zero 
        

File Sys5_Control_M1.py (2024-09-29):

# overall brains script for robot, written by Emma Vladicic and Warren Rogan 

from ECE4191enums import STATE, DIRECTION, ACTION
from Motor_code.encoderClass import SimpleEncoder
from Sys4_Vision import Sys4_Vision

from time import sleep
from math import pi, atan2, sqrt, sin, cos

import RPi.GPIO as GPIO
import GLOBALSM1 #for physical values 

#DEFINE
ANTICLOCKWISE = False
CLOCKWISE = True

#PINS
# Motor Left 
motor2a = 17
motor2b = 27

# Motor Right 
motor1a = 23
motor1b = 24

# Encoder Left 
motor1cha = 13
motor1chb = 19

# Encoder Right 
motor2cha = 5
motor2chb = 6

#Wheel bias
duty_cycle_bias = 0.9645


'''
README FOR THIS CLASS
This class is the combination of all the parts for milestone 1
It uses the Sys4_Vision class to detect and return the location and distance of the tennis ball
It also uses the SimpleEncoder class to get the distance traveled. 

To use this create an instance of the class
then add a call to the release function to ensure that upon completion of the program the GPIO pins are released.
then between the creation and release call add your function calls to get the robot to move and complete actions 

Functions with a _ at the start should only be used inside other functions

External functions are:
    Calibration Test: use this to ensure that the motor pins are correct, the robot should move forwards, 
    backwards, turn left then turn right. Use this the determine if the pins have been plugged in correctly. 
    release: call this to disconnect from the pins to prevent pins being driven when they should not be
    GoTo: takes in an X and Y coordinate in terms of the start position to go to, then goes to this location while updating the 
    position and rotation of the robot.
    hitBallBasic: the first hit ball method, limited controls to make movement smooth
    hitBallBetter: hit ball method, attempts to smooth turns to reduce osculations 
    disEngage: used if the robot should have hit a ball, to move back and disengage, then forward to prevent oversteering due to 
    the dolly wheel locking in place. 
    Home: Uses the current X, Y and rotation to go to the home position. Should only be called after functions that update the 
    position of the robot. 
'''


#Milestone 1 controll top level class 
class Sys5_Control:

    def __init__(self) -> None:

        GPIO.setmode(GPIO.BCM) # set pin types 
        # Set up the output pins 
        GPIO.setup(motor1a, GPIO.OUT) 
        GPIO.setup(motor1b, GPIO.OUT)
        GPIO.setup(motor2a, GPIO.OUT)
        GPIO.setup(motor2b, GPIO.OUT)

        # Set up the PWM pins
        self.pwm1a = GPIO.PWM(motor1a,1000)
        self.pwm1b = GPIO.PWM(motor1b,1000)
        self.pwm2a = GPIO.PWM(motor2a,1000)
        self.pwm2b = GPIO.PWM(motor2b,1000)
        self._stop() # prevent random movements
        # create class instances 
        # Ball finding 
        self.vision = Sys4_Vision()

        #Position control
        self.x_pos =0
        self.y_pos = 0
        self.rot =0 
        self.State = None 
        self.EncoderL = SimpleEncoder(motor1cha,motor1chb) # set up Left Motor
        self.EncoderR = SimpleEncoder(motor2cha,motor2chb) # set up right Motor
    
    def _forwards(self,duty_cycle:float)->ACTION:
    
        # input: duty cycle between 0 - 100
        # output: return the state of the robot

        # drive the motor forwards 
        self.pwm1a.start(0)
        self.pwm1b.start(duty_cycle)
        self.pwm2a.start(0)
        self.pwm2b.start(max(duty_cycle*duty_cycle_bias,5))

        return ACTION.FORWARD

    def _backwards(self,duty_cycle:float)->ACTION:
    
        # input: duty cycle between 0 - 100
        # output: return the state of the robot

        # drive the motor forwards 
        self.pwm1b.start(0)
        self.pwm1a.start(duty_cycle)
        self.pwm2b.start(0)
        self.pwm2a.start(max(duty_cycle,5))

        return ACTION.BACKWARD 

    def _turn(self,duty_cycle:float,clockWise:bool)->ACTION:

        # input: duty cycle between 0 - 100, if you want to turn clockwise or anticlockwise 
        # output: return the state of the robot

        if clockWise:
            self.pwm1a.start(0)
            self.pwm1b.start(duty_cycle)
            self.pwm2a.start(max(duty_cycle*duty_cycle_bias,5))
            self.pwm2b.start(0)
            return ACTION.RIGHT
        else:
            self.pwm1a.start(duty_cycle)
            self.pwm1b.start(0)
            self.pwm2a.start(0)
            self.pwm2b.start(max(duty_cycle*duty_cycle_bias,5))
            return ACTION.LEFT

    def _stop(self)->None:
        self.pwm1a.stop()
        self.pwm1b.stop()
        self.pwm2a.stop()
        self.pwm2b.stop()

    #Manual exit function to prevent loss of pin control
    def _exemptExit(self)->None:
        self._stop()
        GPIO.cleanup()
        self.EncoderL.end()
        self.EncoderR.end()
        #self.vision.disconnect()
    
    #Position tracking 
    def _updatePos(self,x_old:float,y_old:float,rot_old:float)->list[float]:
        # get data
        [newL, dirL, oldL] = self.EncoderL.getValues()
        [newR, dirR, oldR] = self.EncoderR.getValues()

        #difference
        delL = abs(newL-oldL)
        delR = abs(newR-oldR)
        #print(delL-delR)
        #get average travelled distance 
        distanceAvg = ((delL*GLOBALSM1.distancePerPulse)+(delR*GLOBALSM1.distancePerPulse))/2 
        #print(distanceAvg)
        x = 0
        y = 0 
        rot = 0 
        #determine direction
        if self.State == ACTION.FORWARD:
            rot = rot_old
            y= y_old+(distanceAvg*sin(rot*pi/180))
            x = x_old+(distanceAvg*cos(rot*pi/180))
        elif self.State ==ACTION.BACKWARD:
            rot = rot_old
            y= y_old-(distanceAvg*sin(rot*pi/180))
            x = x_old-(distanceAvg*cos(rot*pi/180))
        elif self.State == ACTION.LEFT:
            x= x_old
            y = y_old
            delAngle = distanceAvg*360/GLOBALSM1.wheelBaseCircumference
            rot = rot_old+delAngle
        elif self.State == ACTION.RIGHT:
            x= x_old
            y = y_old
            delAngle = distanceAvg*360/GLOBALSM1.wheelBaseCircumference
            rot = rot_old-delAngle
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

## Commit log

2024-07-25 added rpi models
    [RaspberryPiZeroW.SLDPRT, Raspberry_Pi_4_B.SLDPRT]
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2024-08-01 Bulk upload of 3D parts
    Includes:
    Provided Motor
    Baseplate (not perfect, but pretty close)
    Collection box as described in the FAQs
    Galv. Steel Motor Brackets
    Tennis Ball (max size according to regulations)
    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
    [25d-metal-gearmotor-75-99-encoder.step.SLDPRT, Baseplate.SLDPRT, CollectionBox.SLDPRT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]
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2024-08-20 correct wheel base
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2024-08-25 Bulk CAD Upload
    Bulk upload of Solidworks files worked on over the past couple of weeks
    [25d-metal-gearmotor-75-99-encoder.step.SLDPRT, 4WayServoHorn.SLDPRT, 9gMicroServo.SLDPRT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]
2024-08-25 Rename
    Renamed main assembly
    [RobotWholeAssembly.SLDASM]
2024-08-26 CM basics
    [CM_ASS.SLDASM, CM_Base.SLDPRT, CM_Vertical.SLDPRT]
2024-08-27 Camera Mount Update
    Updated adjustable camera mount
    [CM_Base.SLDPRT, CM_Mount.SLDPRT, CM_Vertical.SLDPRT]
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2024-09-03 CAD model update: Rear Bracket
    Updated the rear ramp brackets to work for laser cutting
    [25d-metal-gearmotor-75-99-encoder.step.SLDPRT, 4WayServoHorn.SLDPRT, 9gMicroServo.SLDPRT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]
2024-09-03 Track Model
    Designed track model based on STL
    [Track_2.4.SLDPRT]
2024-09-03 fixed encoder fix
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2024-09-03 Updated parts for Laser Cutting
    [ClawGearKey_Right.SLDPRT, ClawLeftAssembly.SLDASM, ClawRightAssembly.SLDASM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]
2024-09-03 Exported to DXF
    [Ramp.DXF, Ramp.SLDPRT, RampWheelBracket.DXF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]
2024-09-03 Track Prototyping
    Created a test model of the track conveyor system
    [TrackAssemblyTest.SLDASM, Track_2.2_70mm.SLDPRT]
2024-09-04 CAD Update
    [ClawBracket.SLDPRT, ClawBracketRight.SLDPRT, ClawLeft.SLDPRT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]
2024-09-04 Tracks progress
    [ClawBracket.SLDPRT, ClawBracketRight.SLDPRT, ClawGearKey_Right.SLDPRT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]
2024-09-06 fixed an issue with rot
    [Sys5_Control_M2_DRAFT.py, encoderClass.py]
2024-09-08 CAD Update: Wheel and Track
    Updated CAD files to work with new 100mm wheels, and continued work on the conveyor system, adding slave gear mounts and brackets
    [Baseplate.SLDPRT, ClawGearKey_Right.SLDPRT, ClawLeftAssembly.SLDASM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]
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2024-09-10 Wheel Adaptor
    [100mm2shaft.SLDPRT, 100mm2shaft.STL]
2024-09-10 CAD Update
    Kept working on CAD, updates to tracks, camera mount, and track gear mounting + DXF file for Baseplate cutting
    [AngledRampBracket_Left.SLDPRT, AngledRampBracket_Right.SLDPRT, Baseplate.DWG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]
2024-09-10 dxf added
    [Baseplate.DXF]
2024-09-11 Increased size
    [100mm2shaftCap.SLDPRT, 100mm2shaftCap.STL]
2024-09-12 Fixed baseplate
    [Baseplate.SLDPRT, Ramp.SLDPRT]
2024-09-12 added front reinforcement
    [ClawGearKey_Right.SLDPRT, ClawLeftAssembly.SLDASM, ClawRightAssembly.SLDASM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]
2024-09-14 ball shoot
    [BallChute.DXF, BallChute.SLDPRT, RobotWholeAssembly.SLDASM]
2024-09-14 Laser cut bits
    [BallChute.SLDPRT, Ramp.DXF, RobotWholeAssembly.SLDASM]
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2024-09-16 CAD Update: Track Brackets and Chute
    Continued work on mounting brackets
    Warning: Many mates in top-level assembly currently broken
    [Axle.SLDPRT, BallChute.SLDPRT, Cap_DriveGear_Servo.SLDPRT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]
2024-09-17 camera mounting
    [Battery.SLDPRT, CameraLifter.SLDPRT, CameraMountAss.SLDASM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]
2024-09-18 Camera and lipo mounting
    [CameraLifter.SLDPRT, CameraLifter.STL, CameraMountAss.SLDASM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]
2024-09-18 CAD Update: Track gear axles and caps
    [Axle.SLDPRT, ClawGearKey_Right.SLDPRT, ClawLeftAssembly.SLDASM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]
2024-09-18 CAD Update: Servo mounting and other conveyor work
    [Axle.SLDPRT, Axle_Cap.SLDPRT, Cap_DriveGear_Servo.SLDPRT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]
2024-09-18 CAD Update: Minor
    [GearMount_Servo.SLDPRT, GearMount_ServoSpacer.SLDPRT, HorizontalGearSpacer.SLDPRT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]
2024-09-18 removed try except
    removed try except code in the main function of code bc thought if was causing errors
    [Sys5_Control_M2_DRAFT.py]
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2024-09-19 reduced hole size
    [WireHousing.SLDPRT]
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2024-09-20 fixed distance from box values
    [Sys4_Vision.py, Sys5_Control_M2.py, Sys5_Control_M2_DRAFT.py]
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2024-09-24 Fixed line detection issue
    [Sys4_Vision.py, Sys5_Control_M2.py, Sys5_Control_M2_DRAFT.py]
2024-09-26 addded part
    [MotorDriverRaiser.SLDPRT, MotorDriverRaiser.STL]
2024-09-27 PCB holder
    [PCBHolder.SLDPRT, PCBHolder.STL]
2024-09-30 new mount
    [CameraLifter.SLDPRT, CameraMountAss.SLDASM, ClawGearKey_Right.SLDPRT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]
2024-09-30 added new camera mount
    combines prints to reduce overlap and improve space usage
    [NewServoMountSpacer.SLDPRT, NewServoMountSpacer.STL]
2024-09-30 CAD Update: New MG995 Servo and brackets
    [AlignmentAssembly_GearServo.SLDASM, Assem1.SLDASM, ClawGearKey_Right.SLDPRT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]
2024-09-30 Added RC control of the conveyer
    addition is untested
    [NewServoMountSpacer.SLDPRT, NewServoMountSpacer.STL]
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2024-10-02 Funnel Parts
    [ClawGearKey_Right.SLDPRT, ClawLeftAssembly.SLDASM, ClawRightAssembly.SLDASM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]
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2024-10-03 No Change: Solidworks being weird
    [ClawGearKey_Right.SLDPRT, ClawLeftAssembly.SLDASM, ClawRightAssembly.SLDASM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]
2024-10-03 Extra Tension Gear work
    [Axle.SLDPRT, DiagonalGearSpacer.SLDPRT, GearMount_Servo.SLDPRT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]
2024-10-03 CAD Cleanup
    Removed most depreciated parts from the main assembly and fixed some mates
    [GearMount_Servo.SLDPRT, GearMount_ServoSpacer.SLDPRT, HorizontalGearSpacer.SLDPRT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]
2024-10-03 Thursday Lab: Extra parts
    Extra parts modelled in Thursday's lab. Quick fixes
    [RampFix.SLDPRT, SupportBracket.SLDPRT]
2024-10-04 CAD Update: Ramp Transition
    [RampFix.SLDPRT, RampFix_Bracket.SLDPRT, RobotWholeAssembly.SLDASM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]
2024-10-04 added funnel cut file
    [BallChute.SLDPRT, Funnel.DXF, FunnelAdaptor.SLDPRT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]
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2024-10-04 CAD Update: DiagonalSupport
    Reduced length of diagonal support by 10mm to hopefully improve tension and fix number of links to a multiple of 5
    [DiagonalGearSpacer.SLDPRT, RampFix.SLDPRT, RobotWholeAssembly.SLDASM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]
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2024-10-04 CAD Update: Rear Switch
    [GearMountSpacer.SLDPRT, GearMount_new.SLDPRT, HM_SidePate.SLDPRT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]
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2024-10-05 Even more hail mary
    [HM_Conveyer.SLDASM, HM_HUBCENTRE.SLDPRT, HM_HUBCENTRE.STL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]
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2024-10-06 CAD Update: New Drive gear
    [RobotWholeAssembly.SLDASM, TrackAssembly.SLDASM, TrackSegment.SLDASM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]
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2024-10-07 CAD: New Part: Large Gear
    [TensionGear.SLDPRT]
2024-10-07 CAD Update: Track Pincher added
    [Axle.SLDPRT, HorizontalGearSpacer.SLDPRT, MG995 Assembly.SLDASM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]
2024-10-07 CAD Update: Small extras for conveyor fine tuning
    [MG995 Assembly.SLDASM, RampFix.SLDPRT, RampTrackChuck.SLDPRT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]
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2024-10-09 fixed colour issues
    [HM_HUBCENTRE6.SLDPRT, HM_HUBCENTRE6.STL]
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
